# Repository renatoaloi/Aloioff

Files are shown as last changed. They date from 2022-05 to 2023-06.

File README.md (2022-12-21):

# Aloioff

## Introdução

Aloioff é um dispositivo de acionamento de cargas pela rede, compatível com Alexa, Google Home e Smarthphones.

Clone do Sonoff, mas com a vantagem do ESP8266 ser removível e reprogramável, ou seja, é um kit de desenvolvimento IoT!

## Preparação do Ambiente

- Primeiro você precisará fazer o download da IDE do Arduino:
  - https://www.arduino.cc/en/software
- Depois da IDE do Arduino ser instalada, siga o tutorial abaixo para configurar o pacote do ESP8266:
  - https://www.filipeflop.com/blog/programar-nodemcu-com-ide-arduino/
- Depois de tudo configurado, selecione a board `Generic ESP8266 Module` no menu `Tools` da IDE do Arduino.
- Para finalizar, precisaremos de um plugin chamado `ESP8266 LittleFS Data Upload`.
  - https://github.com/earlephilhower/arduino-esp8266littlefs-plugin

Pronto! O ambiente necessário foi instalado!

## Compilação e Publicação

- Primeiro conecte o ESP8266 na porta USB através do programador USB:
  - https://www.filipeflop.com/produto/adaptador-usb-para-modulo-wifi-esp8266-esp-01
- Selecione o menu `Tools`, em seguida `Board` e selecione a placa `Generic ESP8266 Module`.
- Selecione a porta USB correta no menu `Tools` e efetue o upload do código no ESP8266.
- Selecionar o menu `Tools` e depois `Flash Size` e escolher a opção `1M FS:144Kb`.
- Terminado o upload você precisará subir os arquivos da pasta `data`, para isso acesse o menu `Tools` novamente e clique no plugin `ESP8266 LittleFS Data Upload`.

Pronto! O código e os dados estão publicados no ESP8266!

## Como utilizar

- Pressione o botão do Aloioff por 5 a 10 segundos para ele entrar em modo de fábrica.
- Utilize seu smartphone para conectar na rede `ALOITECH` que o ESP8266 criará no modo de fábrica.
  - A senha é `12345678`
- Feito isso, utilize o navegador de internet do seu smartphone para acessar o endereço `http://10.0.0.1`
- Configure o nome do dispositivo e os dados de acesso do seu WiFi.
- Clique no menu `Reiniciar` e depois no botão `Reiniciar` para confirmar a ação.

Pronto! Seu Aloioff está configurado e funcionando!

## Registrando na Alexa

- Você só precisa registrar o seu novo dipositivo na Alexa, através do aplicativo da Alexa, conforme esse tutorial:
  - http://blog.arduinoomega.com/automacao-residencial-com-esp8266-e-alexa/
  - Avance até o tópico `Conexão pelo aplicativo Alexa` para aprender como configurar o Aloioff no aplicativo da Alexa.

## Esquema elétrico

O esquema elétrico do Aloioff é bem simples e é ligado em série com a carga, mas é possível também fazer o acionamento em paralelo com um interruptor.

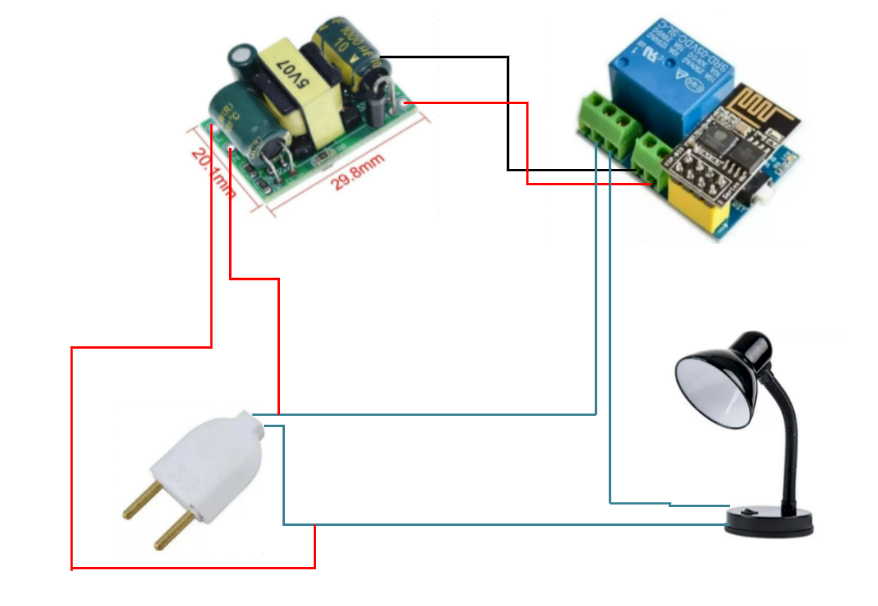
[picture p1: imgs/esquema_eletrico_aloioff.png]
Esquema elétrico do Aloioff


## Hack necessário para funcionar

Infelizmente os módulos de relê chineses tem um problema crônico em que o ESP01 não inicia sozinho, por causa de um projeto malfeito pelos chineses.

Para contornarmos esse problema, precisamos de um `hack`, ou seja um ajuste técnico, que são dois resistores de 10K conectados no pino `3V3` e nos pinos `EN` e `GPIO0`.

E não esqueça de ligar o botão também conforme mostra o esquema abaixo:

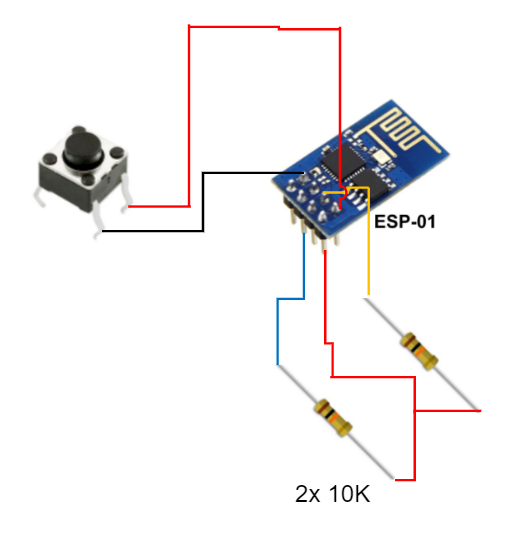
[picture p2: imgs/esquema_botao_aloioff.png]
Esquema botão do Aloioff


## Projeto da Caixa

- Na pasta `case` você encontrará os arquivos fonte `*.scad`, tanto da caixa quanto da tampa.
- Para editar os arquivos `*.scad` utilize o editor open source chamado `openSCAD`.
- Se quiser imprimir diretamente, utilize os arquivos `*.stl` que já estão prontos para imprimir.
- Utilize a configuração `Draft - 0.2mm` para imprimir.

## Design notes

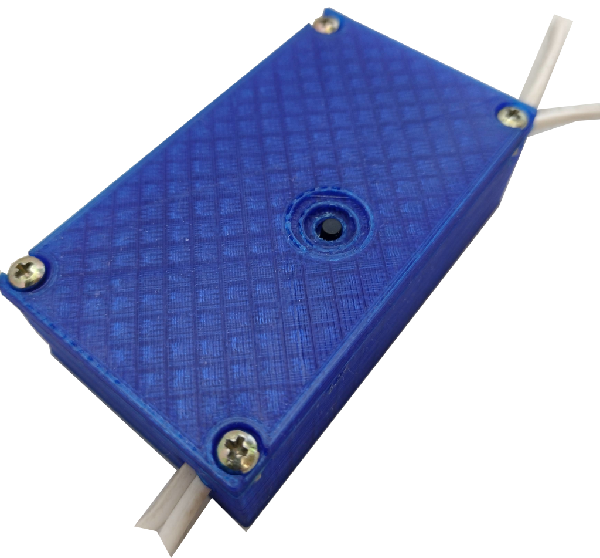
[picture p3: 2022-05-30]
imgs/foto_case1.png

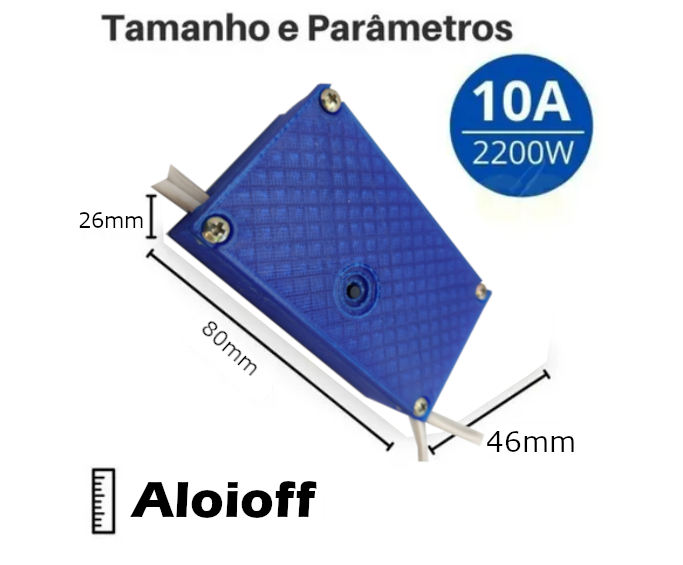
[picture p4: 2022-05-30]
imgs/foto_medidas.png

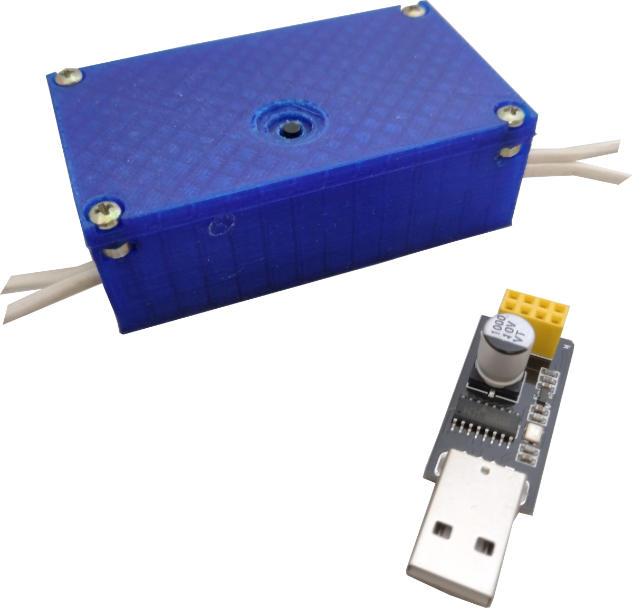
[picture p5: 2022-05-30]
imgs/foto_case_com_usb.png

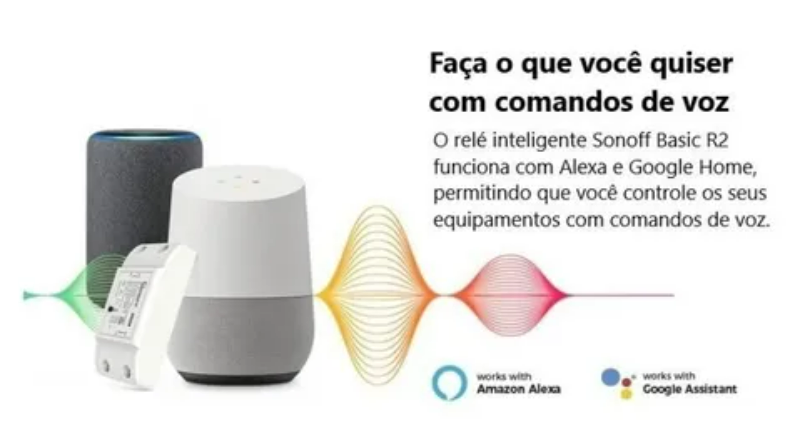
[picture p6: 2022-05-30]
imgs/foto_alexa_okgoogle.png

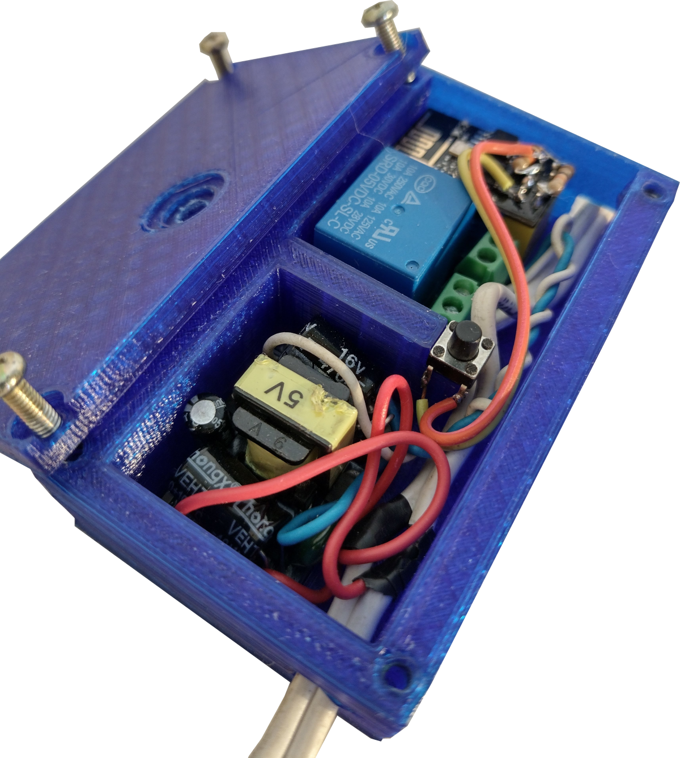
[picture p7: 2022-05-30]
imgs/foto_case2.png

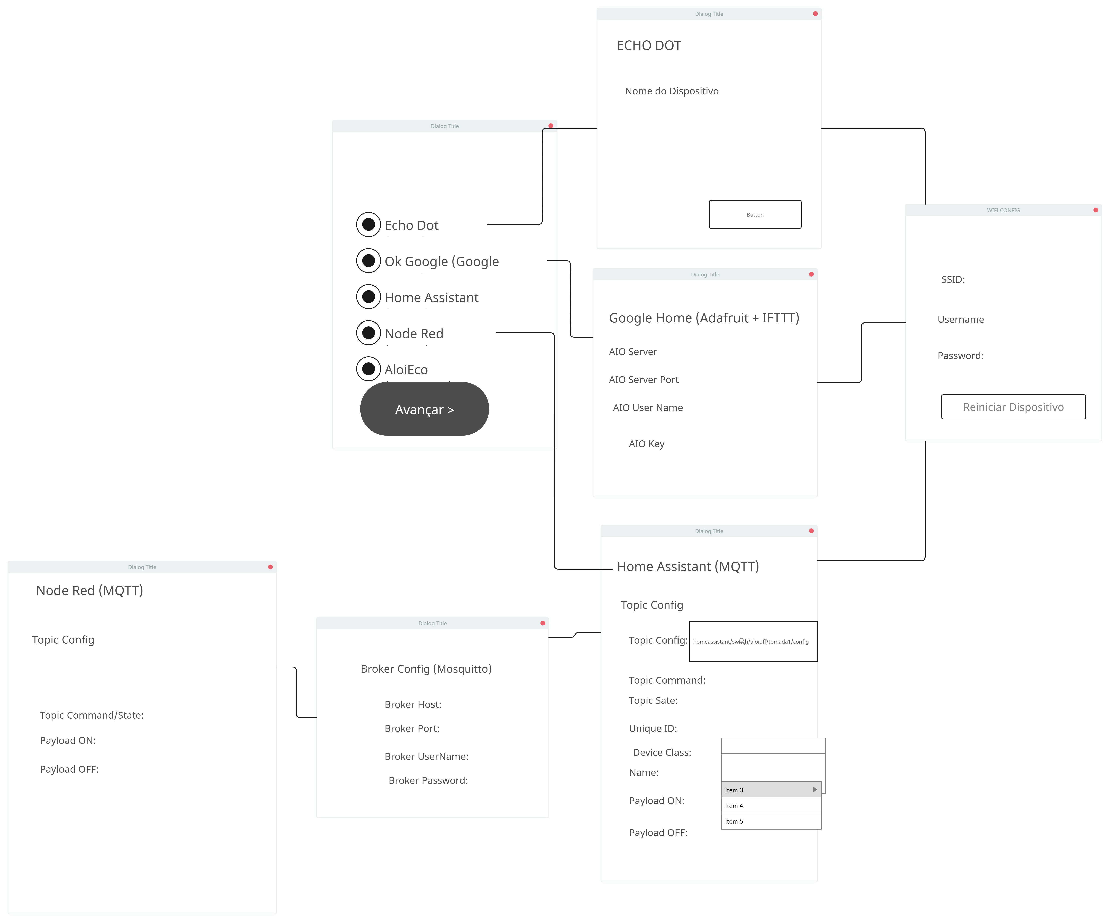
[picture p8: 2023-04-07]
imgs/Aloiosca_Config_Wizzard_Wireframe.jpg

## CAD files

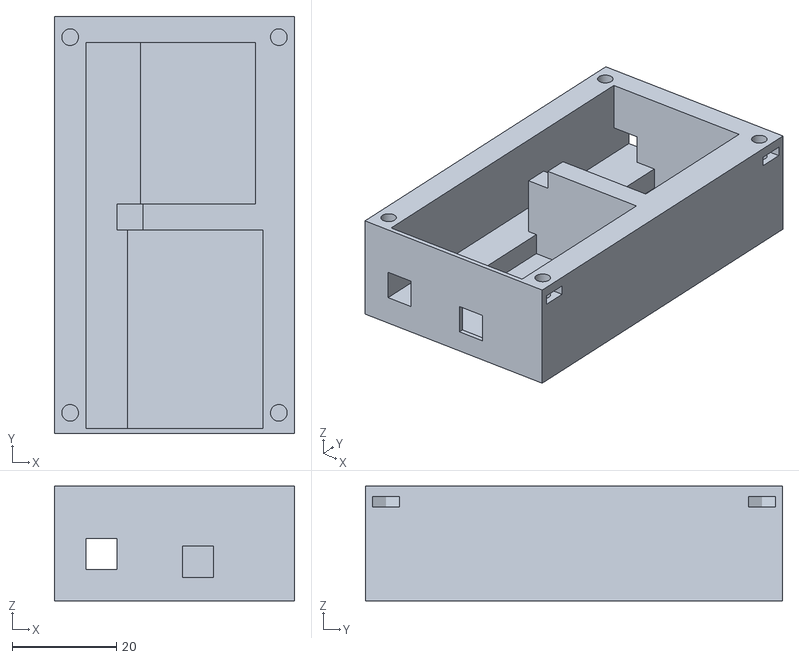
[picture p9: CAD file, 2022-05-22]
case/Case.stl
46.0 x 80.0 x 22.0

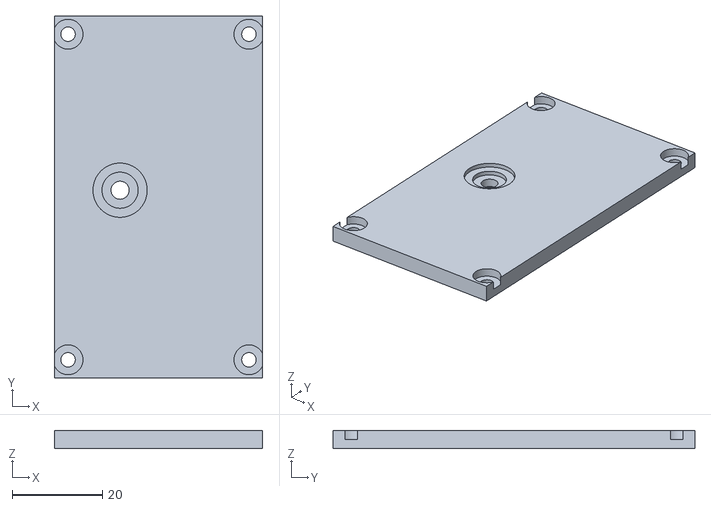
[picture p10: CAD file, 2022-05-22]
case/CaseTop.stl
46.0 x 80.0 x 4.00

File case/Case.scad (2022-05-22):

h = 22;


module cuboPrincipal() {
    cube([30, 80, h]);
}

module cuboCanaleta() {
    translate([-8,0,0])
    cube([8, 80, h]);
}

module espacoEsp8266() {
    cube([26,38, h+1]);
}

module espacoFonteAlimentacao() {
    cube([22,31,h+1]);
}

module espacoSeparador() {
    cube([10,38, h+1]);
}

module furoBotaoReset() {
    translate([12.5,-1,1.5+3])
    cube([6, 8, 6]);
}

module furoPassagemFio(offSet) {
    translate([-6,-1+offSet,6])
    cube([6, 8, 6]);
}


module blocoComEspacos() {
    difference() {
        cuboPrincipal();
        // rasgos
        translate([2,1,1.5])
        espacoEsp8266();
        translate([-1,1,6])
        espacoEsp8266();
        translate([4.5,39+5,1.5])
        espacoFonteAlimentacao();
        translate([-1,39+5,6])
        espacoFonteAlimentacao();
        // furos
        furoBotaoReset();
    }
}


module pecaPronta() {
    blocoComEspacos();

    difference() {
        cuboCanaleta();
        translate([-6,1,6])
        espacoEsp8266();
        translate([-6,39+5,6])
        espacoFonteAlimentacao();
        translate([-6,38,6])
        cube([34,5+2, 18]);
        // furos
        furoPassagemFio(0);
        furoPassagemFio(75);
    }
}

module pecaProntaNoLugar() {
    translate([8,0,0])
    pecaPronta();
}

module porca() {
    cylinder(h=2, r=3, $fn=6);
    translate([-6,-2.6,0])
    cube([6,5.2,2]);
}

module furoPorca() {
    cylinder(h=40, r=1.6, $fn=64);
}

module parede() {
    translate([-4,0,0])
    cube([4, 80, h]);
}

module parede2() {
    translate([38,0,0])
    cube([4, 80, h]);
}

module furacao1() {
    translate([-1,4,18])
    porca();
    translate([-1,4,8])
    furoPorca();
}

module furacao2() {
    onde=40-1;
    translate([onde,4,18])
    rotate([0,0,180])
    porca();
    translate([onde,4,8])
    furoPorca();
}

module pecaProntaNoLugarComFuros() {
    translate([4,0,0])
    difference() {
        union() {
            pecaProntaNoLugar();
            parede();
            parede2();
        }
        furacao1();
        translate([0,72,0])
        furacao1();
        furacao2();
        translate([0,72,0])
        furacao2();
    }
}

difference(){
    pecaProntaNoLugarComFuros();
    translate([11,38,22-4])
    cube([6,7,5]);
}

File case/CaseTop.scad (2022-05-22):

h = 4;

module furoPorca(r) {
    cylinder(h=40, r=r, $fn=64);
}

module furacao1(fh, fp) {
    translate([-1,4,fh])
    furoPorca(fp);
}

module furacao2(fh, fp) {
    onde=40-1;
    translate([onde,4,fh])
    furoPorca(fp);
}

module cuboPrincipal() {
    translate([-4,0,0])
    cube([46, 80, h]);
}

module tampa() {
    translate([4,0,0])
    difference(){
        cuboPrincipal();

        furacao1(-1, 1.6);
        translate([0,72,0])
        furacao1(-1, 1.6);
        furacao2(-1, 1.6);
        translate([0,72,0])
        furacao2(-1, 1.6);
        
        cabeca=3.3;
        furacao1(2, cabeca);
        translate([0,72,0])
        furacao1(2, cabeca);
        furacao2(2, cabeca);
        translate([0,72,0])
        furacao2(2, cabeca);
    }
}

difference(){
    tampa();
    translate([12+2.5,39+2.5,-1])
    cylinder(h=10, r=2, $fn=64);
    translate([12+2.5,39+2.5,2])
    cylinder(h=10, r=4, $fn=64);
    translate([12+2.5,39+2.5,3])
    cylinder(h=10, r=6, $fn=64);
}

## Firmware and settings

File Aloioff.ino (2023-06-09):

#include "Aloioff.h"

void setup()
{
  if (DEBUG)
  {
    Serial.begin(115200);
    delay(500);
  }

  pinMode(LED2, OUTPUT);
  digitalWrite(LED2, HIGH);
  analogWrite(LED1, 0);

  initUserConfig();
  configButton();

  if (getModoAP())
  {
    // Modo AP
    ligarModoAP();
  }
  else
  {
    // Modo de operacao STATION
    ligarModoSTA();

    if (!IsWiFiNotConnected())
    {
      // depois que modo STA for configurado
      if (getModoOperacao() == 1)
      {
        initAlexa();
      }
      else if (getModoOperacao() == 2)
      {
        if (DEBUG) Serial.println("Iniciando modo #2");
        initOkGoogle();
      }
      else if (getModoOperacao() == 3)
      {
        if (DEBUG) Serial.println("Iniciando modo #3");
        initHomeAssistant();
      }
      else if (getModoOperacao() == 4)
      {
        if (DEBUG) Serial.println("Iniciando modo #4");
        initNodeRed();
      }

      // Starting discovery UDP service
      beginUDP();
    }
    else
    {
      desligarModoSTA();
    }
  }
}

void loop()
{
  if (checkButton()) {
    saveUserConfig("", "", "", "", 0, true, "", 0, "", "", "", "", "", "", "", "");
    saveModoAP(true);
    resetDevice();
  }
  if (getModoAP()) {
    dnsServer.processNextRequest();
    handleWebServer();
  }
  if (!getModoAP()) {
    if (getModoOperacao() == 1)
      alexaHandle();
    else if (getModoOperacao() == 2)
      handleOkGoogle();
    else if (getModoOperacao() == 3)
      handleHomeAssistant();
    else if (getModoOperacao() == 4)
      handleNodeRed();
    handleUDP();
  }
}

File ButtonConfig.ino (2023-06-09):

static unsigned long contaTempo = 0;
static int contaVezes = 0;
const int limiteVezes = 7;
const int intervaloTempo = 300;
static bool buttonPressed = false;

void resetDevice() {
  ESP.restart();
}

void configButton() {
  pinMode(BUTTON, INPUT);
  digitalWrite(BUTTON, HIGH);
  contaTempo = millis();
}

bool checkButton() 
{
  if (contaVezes >= limiteVezes) {
    buttonPressed = false;
    contaVezes = 0;
    contaTempo = millis();
    return true;
  }
  if (!digitalRead(BUTTON) && contaTempo < millis()) {
    buttonPressed = true;
    atualizaTempo();
    contaVezes++;
  }
  else if (digitalRead(BUTTON) && contaTempo > millis()) {
    contaVezes = 0;
    atualizaTempo();
  }

  if (digitalRead(BUTTON) && buttonPressed) {
    buttonPressed = false;
    contaVezes = 0;
    contaTempo = millis();
    if (relayStatus) {
      turnOffRelay();
    } 
    else {
      turnOnRelay();
    }
  }
   
  return false;
}

void atualizaTempo() {
  contaTempo = millis() + intervaloTempo;
}

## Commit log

2022-05-22 cad files upload
    [Case.scad, Case.stl, CaseTop.scad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]
2022-05-22 update readme with stl
2022-05-22 factory reset button
    [Case.scad, Case.stl, CaseTop.scad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]
2022-05-22 button on port 3
2022-05-29 hack dos resistores de 10k
2022-12-10 new feature for relay manual action
2022-12-11 projeto natalino live de 10/12/22
2022-12-13 Ajuste na configuração do modo de operação
2022-12-14 ajustes modo de operação AP
2022-12-19 removing serial print
2022-12-20 pagina de acionamento manual funcionando invertidamente
2022-12-21 ajustes finais de logica invertida
2022-12-24 tentativa de ajuste
2022-12-29 primeiros ajustes de refatoração [UserConfig]
2022-12-30 bug fixes in refactoring
    [Wifi.ino]
2023-01-04 ajustes de html e javascript
2023-04-03 esquema de páginas de config
2023-04-14 ok google relay action
2023-04-14 factory button
2023-04-14 init google with relay
2023-04-21 char to byte fix
    [Webserver.ino]
2023-06-09 leds and button new function
